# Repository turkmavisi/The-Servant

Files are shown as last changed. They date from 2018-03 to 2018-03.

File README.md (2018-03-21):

# The-Servant

## Autonomous Garbage Collector Robot Project of JCN Electronics

The Servant Project includes the complete design, production and documentation processes of an autonomous garbage collector robot which detects undesirable objects in its own specified area and clears the area off from these undesirable objects by dropping them to its opponent’s field. The Servant is created as a scalable product prototype for mass production which belongs to JCN Electronics who is the virtual company that is founded and managed by the Project Team as Middle East Technical University Electrical and Electronics Engineering Undergraduate Senior Design (Dissertation) Project.

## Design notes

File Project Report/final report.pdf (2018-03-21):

## Table of Contents

## 1. EXECUTIVE SUMMARY

Encyclopedia Britannica defines the word engineering as “the application of science to the

optimum conversion of the resources of nature to the uses of humankind”. In parallel to this

definition, throughout history; to do research; to design, invent and manufacture products in

order to satisfy our everlasting needs and demands within the restrictions of our limited

resources have been among the main purposes of engineering. Consequently, our expanded

horizons have led us to feel the need to have robots that will do the hard work instead of us,

and maybe, for us.

In the last decade, as the robot systems became more and more widespread, autonomous

devices have experienced a rise of attention. The applications of autonomous devices are

numerous. Therefore, studying these concepts and designing and manufacturing a product

that can achieve this, are among the needs of today’s academic and industrial world.

Through this document, JCN, a newly established company aiming at simple, yet elegant

solutions to real life problems according to the needs of their customers, presents their main

solution steps: Their conceptual design for the problem of constructing a robot that will clear

its own area off undesirable objects.

The final product incorporates several subsystems such as motion system, field and position

system, target and fence detection system, catching and throwing system and power

system. The philosophy of the design is based on simplicity and robustness, as a commercial

product would be restricted mostly by these specifications. The proposed system comes into

prominence with its detection system and its effective catching and throwing system as the

rest of the report will show.

JCN has been working on this project extensively and continuously for the last 7 months. To

design and manufacture such systems require a substantial amount of knowledge about

signal processing, control theory and robotics. Therefore, JCN, as a company proud to work

on such a project and each and every team member is happy to contribute to it. Not only is

this project a road to synthesize the theoretical knowledge they have acquired so for but

also, an opportunity to learn a lot more.

## 2. BRIEF INTRODUCTION

Recently founded by five ambitious engineers, JCN is a company focusing on robotics,

control systems and digital signal processing. Each of these five group members has different

major fields of study and they encompass a wide range of professional interests. Believing

that the interdisciplinary study is an integral part of their problem solving process, JCN is

glad to have this diversity in the company.

For their first project, JCN is now working on to design and build “A robot which clears its

own area off undesirable objects.” In this project, JCN provides their customers with a

Servant robot, adjustable field and adjustable objects, along with the deliverables that come

with the end product. The main operation of the product is to detect the undesirable object

with the help of the sensors, catch it and throw it to the other field without colliding the

fence or the other robot. The design basically consists of the following subsystems:

- Microcontroller subsystem consisting of two Arduino Nano to integrate all

individual subsystems under a complete system,

- A power subsystem to distribute the power to the product efficiently,
- A motion subsystem consisting of the main body of the vehicle, motors and

motor driving circuitry,

- A field detection subsystem consisting of four CNY sensors at the corners of the

robot to detect the borders of the field,

- An object detection subsystem consisting of two ultrasonic sensors to detect the

targets (undesirable objects) and the fence,

- A catch and throw subsystem consisting of a creative mechanic design working

with one servomotor and 2 stepper motors.

The main aim of this report is to give the detailed information about JCN’s final product for its latest project. In this report; after presenting the company and briefly explaining the main system, each sub-block has been presented. Technical details about the product, specifications and test results have been given. Moreover; deliverables and overall cost of the product have been discussed.

## 3. COMPANY ORGANIZATION

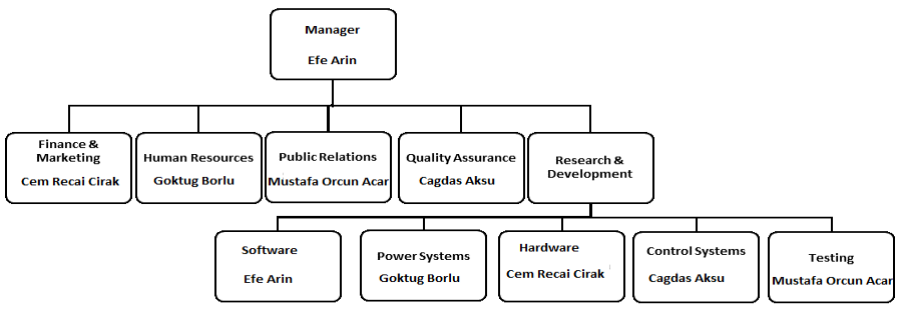
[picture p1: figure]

Figure 1: Company Organization

Hata! Başvuru kaynağı bulunamadı. shows the Company Organization. In this Figure, the divisions are done using the conceptual relationship in the company. All five members have responsibilities in the Management and Research & Development parts.

## 4. DESIGN DESCRIPTION

JCN has designed the robot having 4 sub-blocks, which are intended to function for

specific jobs to meet the all requirements of the project. The sub-systems perform

individually, and they are controlled by common or different DC motors and microcontroller.

Main Requirements:

- Robots should not exceed the boundaries and fence
- Speed and detection is important because of the limited time and opponents.
- No hard wiring is allowed cross the field boundaries.

Before going to next step, main hardware components of the servant project are;

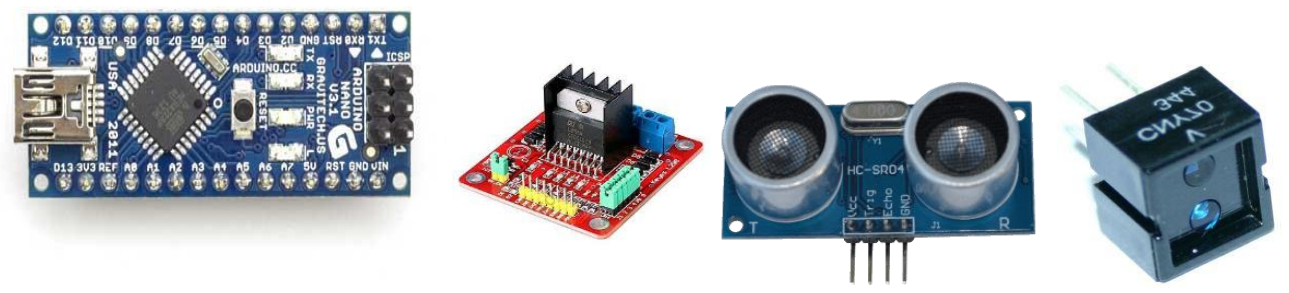
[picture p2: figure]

Figure 2 Main components of the Servant

### 4.1 System Modules

Motion System and Microcontroller: This system is basic response to movement of

robot. There is not complex as other three subsystems but it is important as them. Therefore

JCN has spared necessary time to develop this system. The purpose of this system is to enable

the robot move stably when makes detection and disposing. This system contains two high-

torque DC motors with their wheels and one dummy wheel

For microcontroller part, JCN decided to use two separate ardunio nano to perform

multiple task functionality in inexpensive way. Why is this way inexpensive? The answer is

quite open; for multitasking functionality; high –level microcontrollers such as FPGA should

be used. It is already known that these type microcontrollers are so expensive when compared

with two ardunio nano.

One of the ardunios is used to perform motor driving, target and field detection (takes

the data coming from ultrasonic and contrast sensors).Other one’s usage purpose is

controlling catch and throw mechanism. The advantage of using this method is that we divide

the controls of two main subsystems to two different microcontrollers. By using this way

when the servant throws the garbage, it can continue to detection facility.

Detection System: Since the project is mainly based on the detection of the wastes,

much more time was spend and also much more research was made for this part of the system

modules when is compared other three system modules. At the beginning of the project many

solutions were thought such as image process, ultrasonic sensors etc. by shareholders of JCN.

At the end much more economic and easy way were determined that using ultrasonic sensors

and for this system module. In addition to this for the field detection contrast sensors are used.

Catch and Throw System: This sub-system is designed to send the wastes to

opponent side. This system module is second important part of the whole system. Design

consists of two alternative solutions according to the distance of servant to fence. If the

servant is close enough to fence, then it uses drop functionality otherwise it uses throw

mechanism.

Power System: When this module was designed, JCN considered two main things:

power consumption and high sensitive to environment. Safety is also important but in these

days most of the batteries types can meet this requirement. According to these consideration

power system has designed and completed

### 4.2 System Algorithm

The individual sub systems will be discussed in detail analytically and critically,

however to give the initial and basic logic of the device functioning to the customers, ASMD

type of system algorithm can be examined as in Figure 3.

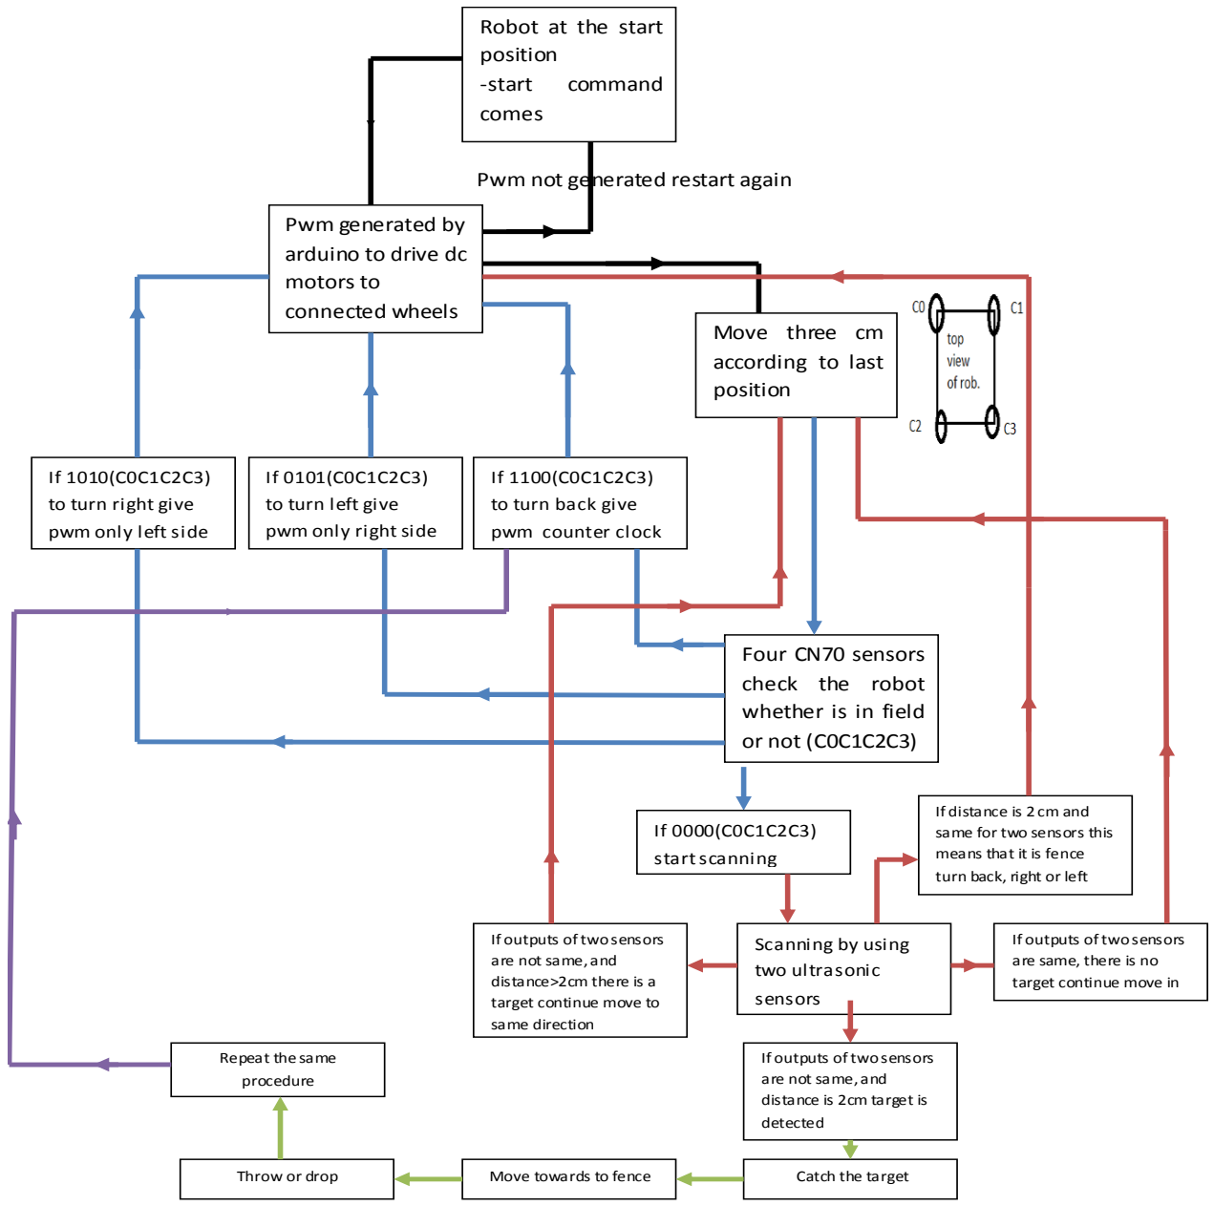
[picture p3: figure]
Pwm not generated restart again; Robot at the start position; -start; command; comes; Pwm generated by arduino to drive dc motors to connected wheels; Move three cm according to last position; Four CN70 sensors check the robot whether is in field or not (C0C1C2C3); If 0101(C0C1C2C3) to turn left give pwm only right side; Scanning by using two ultrasonic; sensors; If 1010(C0C1C2C3) to turn right give; pwm only left side; If 1100(C0C1C2C3) to turn back give; pwm counter clock; start scanning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

Figure 3 ASMD chart of general design

## 5. ANALYSIS OF THE SUBSYSTEMS

The design of the project is composed of 4 sub-blocks, which are motion subsystem, detection subsystem, catch and throw mechanism, finally power system. Before giving detailed information about these systems, you can see the flow diagram of the servant project as below:

START

Initialize the pins and pwm generator to move

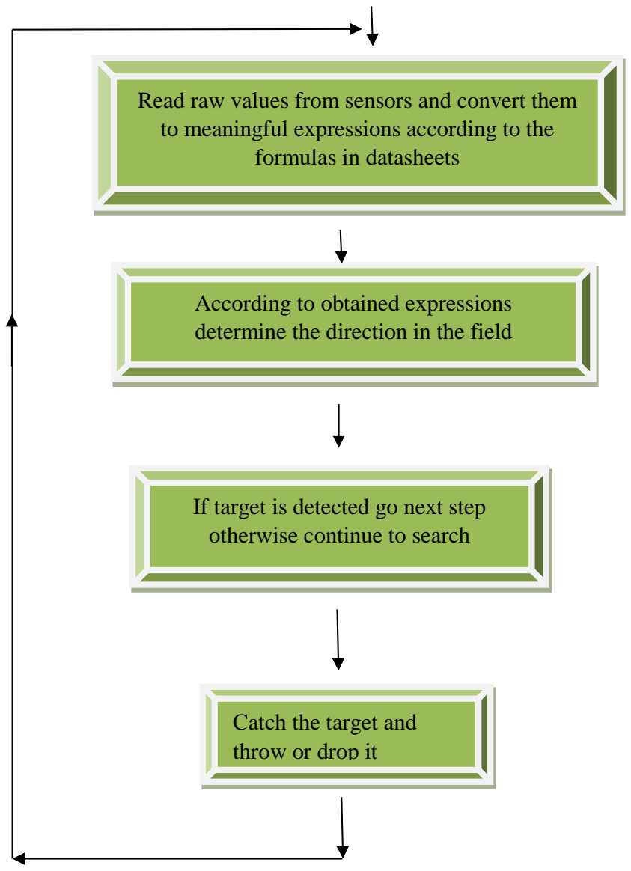
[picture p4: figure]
formulas in datasheets; According to obtained expressions determine the direction in the field; If target is detected go next step otherwise continue to search; Catch the target and throw or drop it

Read raw values from sensors and convert them to meaningful expressions according to the

### 5.1. Motion and Microcontroller Subsystem

The general solution logic can be seen from the chart below.

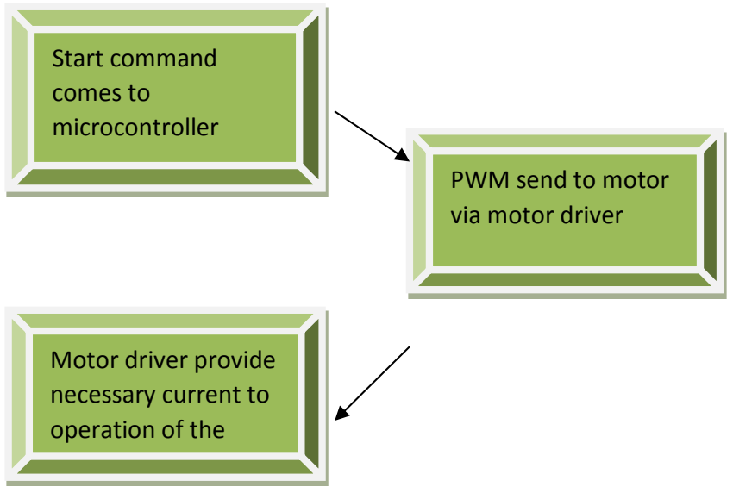
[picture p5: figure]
Start command comes to microcontroller; PWM send to motor via motor driver; Motor driver provide necessary current to operation of the

L298N Motor drive:

Due to that the motor will be requiring more current than the microcontroller pin can

provide, this unit is needed for motor driving. This chip contains dual Full Bridge, which

accept standard TTL logic levels and drive inductive loads such as relays, solenoids, DC and

stepping motors.

The L298N is designed to provide bidirectional drive currents of up to 4 A at voltages

to 46 V. The L298N provides low saturation voltages and over temperature protection. In

addition to this, it provides logical “0” input voltage up to 1.5 V in other words it has high

noise immunity.

The L298N IC receives signals from the microprocessor and transmits this signal to

the motors. It has two voltage pins, one of which is used to draw current for the working of

the L298N and the other is used to apply voltage to the motors. The L298N switches it output

signal according to the input received from the microprocessor. For example: If the

microprocessor sends a 1(digital high) to the Input Pin of L298N, then the L298N transmits a

1(digital high) to the motor from its Output Pin. An important thing to note is that the L298N

simply transmits the signal it receives. It does not change the signal in any case.

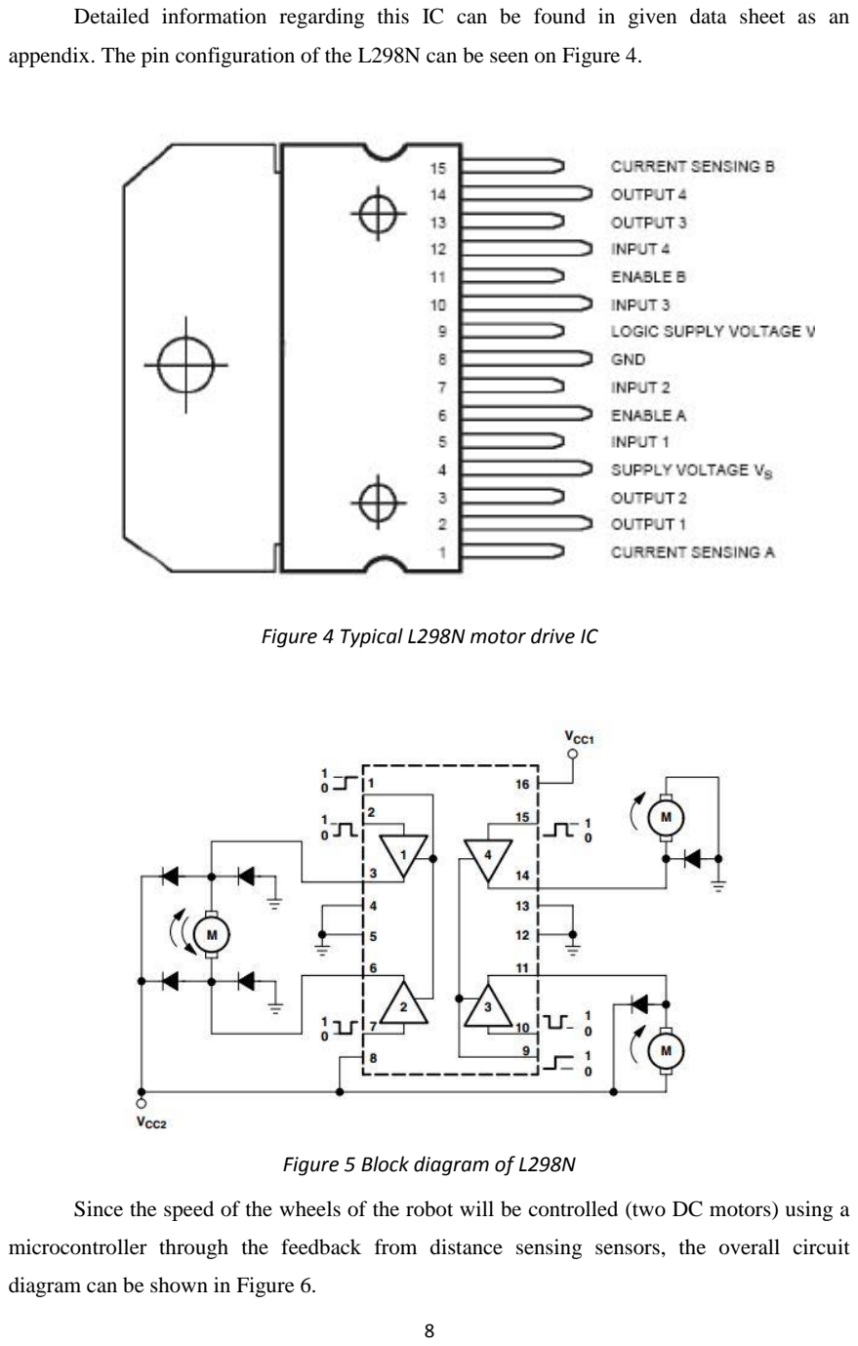
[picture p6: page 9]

Detailed information regarding this IC can be found in given data sheet as an

appendix. The pin configuration of the L298N can be seen on Figure 4.

Figure 4 Typical L298N motor drive IC

Figure 5 Block diagram of L298N

Since the speed of the wheels of the robot will be controlled (two DC motors) using a

microcontroller through the feedback from distance sensing sensors, the overall circuit

diagram can be shown in Figure 6.

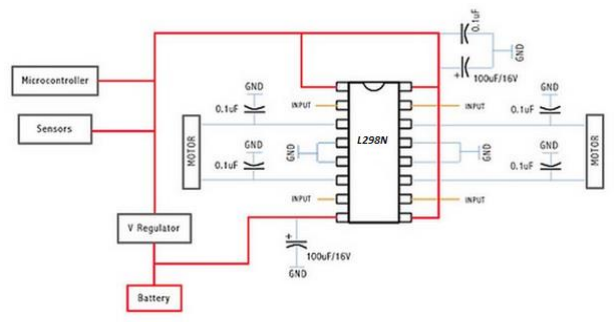
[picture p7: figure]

Figure 6 Circuit diagram of motor driver

According to sensors data microcontroller sends a command (pwm) to driver to made

scanning process on the given field. Detailed information will be given in detection part but

basic principle of the turn right or left based on given pwm to left and right DC motors. In

other words when pwm is only given to right motors, the servant turns left side otherwise

turns right.

Microcontroller & PWM:

The speed for the following mode of operation will be controlled by a well-known

technique of Pulse Width Modulation (PWM). Pulse width modulation is a method for

reducing the amount of power delivered to a DC motor. Instead of reducing the voltage

operating the motor (which would reduce its power), the motor’s power supply is rapidly

switched on and off. The percentage of time that the power is on determines the percentage of

full operating power that is accomplished. This type of motor speed control is also easier to

implement with digital circuitry. It is typically used in mechanical systems that will not need

to be operated at full power all of the time.

The first sub system to be implemented in the project was this sub block (motion system), and

JCN has completed this part with no error rate. This has been achieved thanks to the

successfully planned conceptual design of this sub system, as discussed in detail in the test

procedures & results part of this report.

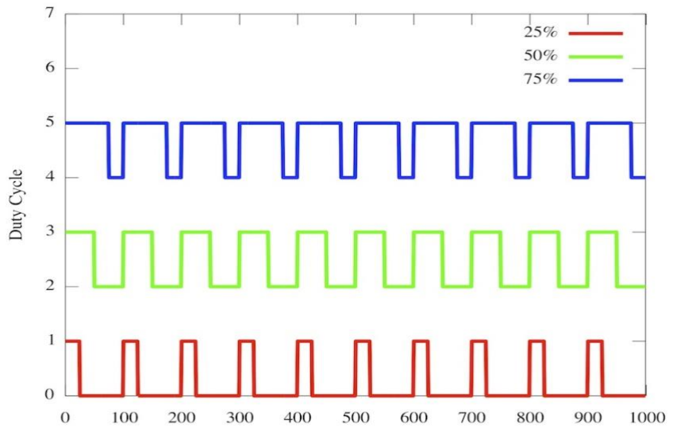
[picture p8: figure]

To implement this method, Arduino has been preferred among other types of

microcontrollers due to the advantages it offers, some of which can be examined as below;

- Inexpensive
- Arduino boards are relatively inexpensive compared to other microcontroller platforms. The

least expensive version of the Arduino module can be assembled by hand, and even the pre-

assembled Arduino modules cost less than $50. Due to these information, it was logical to use

Arduino for cost minimization purposes.

- Cross-platform
- The Arduino software runs on Windows, Macintosh OSX, and Linux operating systems.

Most microcontroller systems are limited to Windows.

- Simple programming environment
- The Arduino programming environment is easy-to-use, and flexible, which reduces the

amount of time allowed for the coding.

Figure 7 PWM with different duty cycle.

### 5.2. Detection Subsystem

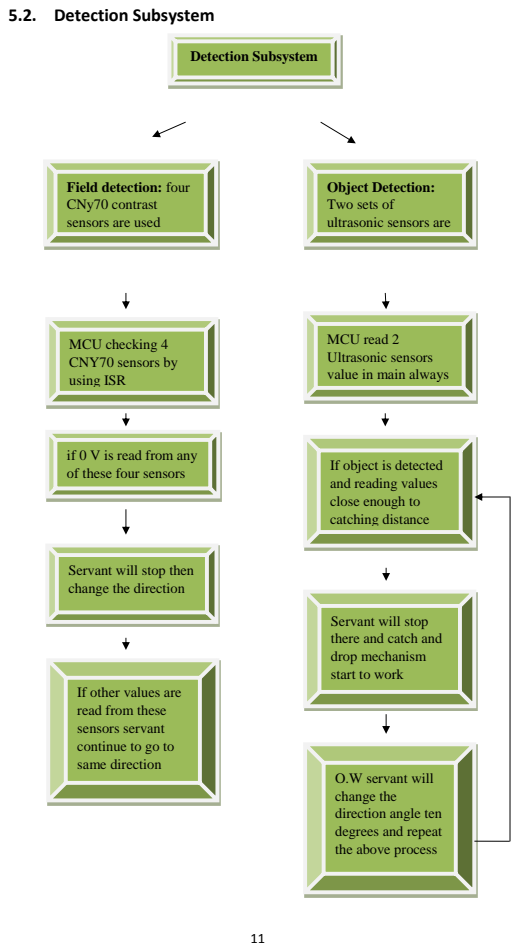
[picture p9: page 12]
MCU checking 4 CNY70 sensors by using ISR; Detection Subsystem

Field detection: four
CNy70 contrast
sensors are used

Object Detection:
Two sets of
ultrasonic sensors are

MCU read 2
Ultrasonic sensors
value in main always

if 0 V is read from any
of these four sensors

If object is detected
and reading values
close enough to
catching distance

Servant will stop then
change the direction

Servant will stop
there and catch and
drop mechanism
start to work

If other values are
read from these
sensors servant
continue to go to
same direction

O.W servant will
change the
direction angle ten
degrees and repeat
the above process

Detection subsystem was divided in two main blocks. These blocks are field detection

and target detection.

Field detection subsystem: is used to identify field by remaining within the field borders and

to specify the position of the robot and the direction that it fronts on to. In this part, mainly

two CNY70 contrast sensors are used. These sensors are emplaced on the leading edge of

robot base 1 cm above the field floor as one on the leftmost and one on the rightmost. In

addition, for the sake of to ease the detection process, floor of the field is designed in white

color with 2.5 cm width black borders to make a contrast between field and borders. During in

motion, the robot checks analog data came from both CNY70 sensors continuously and

interprets it as digital data by comparing it with a threshold value which is decided according

to experimental measurements. (Using analog data provides capability to make a reasonable

comparison with an adjustable threshold value for deciding the contrast level in different

environments by neutralizing the undesired distractive environmental effects.) In general case,

values read from both sensors are expected under the threshold. Remaining all three cases are

considered as primary emergency cases and less than one of these cases related immediate

action algorithm is run. These algorithms stern to the robot into the field back and end the

emergency case in the shortest time possible. Brief description about CNY70; is a reflective

sensor that includes an infrared emitter and phototransistor in a leaded package which blocks

visible light. You can see CNY70 and test configuration from Figure 8.

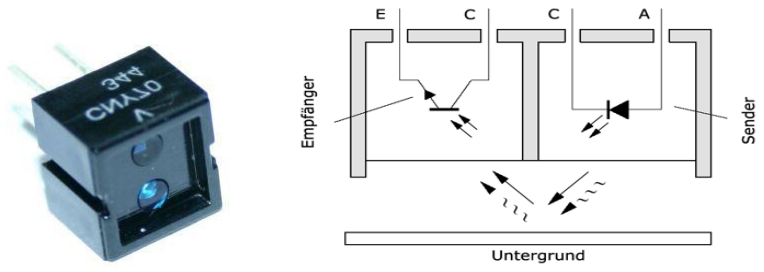
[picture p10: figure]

Figure 8 Working principle of contrast sensor

Object Detection Subsystem: Object detection subsystem is used to search and detect the

targets and the fence. This subsystem consists of two nested parts as fence detection and

target detection. In this subsystem, mainly two Ultrasonic sensors are used. The working

principle of ultrasonic sensors is given on Figure 9.

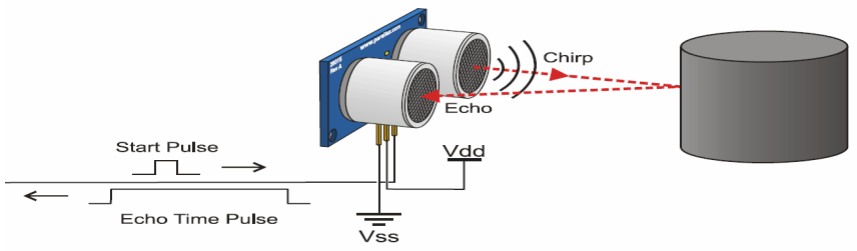
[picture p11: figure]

Figure 9 Working principle of ultrasonic sensor

Object detection subsystem also consists of two separate parts:

Fence Detection: Fence detection part aims to avoid possible crashes between the robot and

the fence while searching for targets and to detect and to close through the fence with the right

angle after a target was captured. The robot decides that the fence is detected if the higher

sensor data implies that there is an object.

Target Detection: Target detection part aims to search and to find the targets. In this part,

there are three possible cases. First, if the lower sensor implies that there is no object, then the

robot decides that there is no target in the scope. In this situation servant change direction

angle and scan again object in the range of ultrasonic sensors. This process is continued until

the object is found or 360 degrees are completed. If object cannot found in this process

servant continue to movement in random direction 2 seconds then repeat the same process.

Second, if both sensors imply that there is an object and their data values approximately the

same, then the robot decides that there is no target in the scope and the fence is detected.

Third, if both sensors imply that there is an object and their data values strictly different

(expectedly data value comes from the lower sensor is greater), then the robot decides that a

target is detected. When target is detected MCU control the distance whether garbage closes

enough to catch mechanism. If it is close catch and drop/throw mechanism will start otherwise

servant go to object until the sufficient distance will be caught

### 5.3. Catch and Throw Subsystem

Before going deep in this subsystem, Figure 10 and Figure 11 are given in order to help you to construct the real mechanism in your brain before reading detailed explanations.

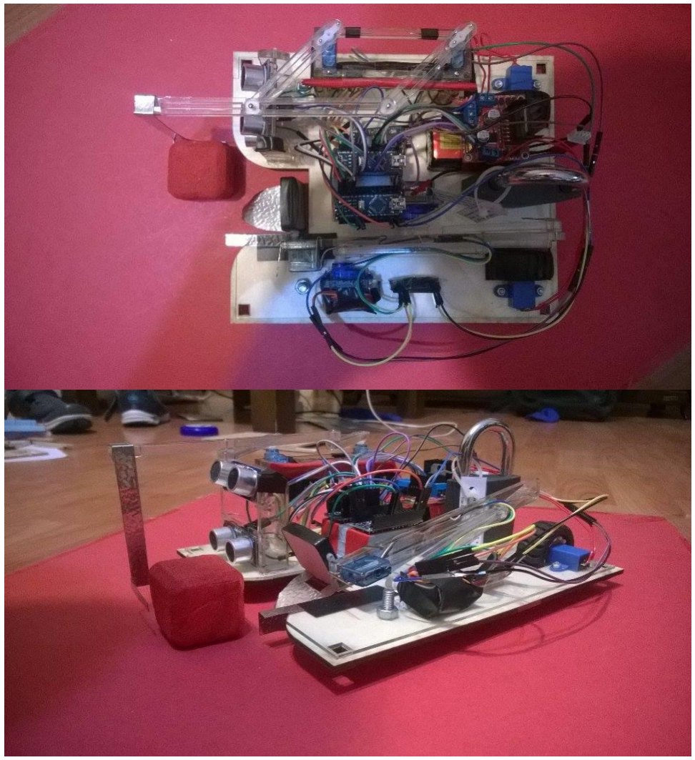
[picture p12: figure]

Figure 10

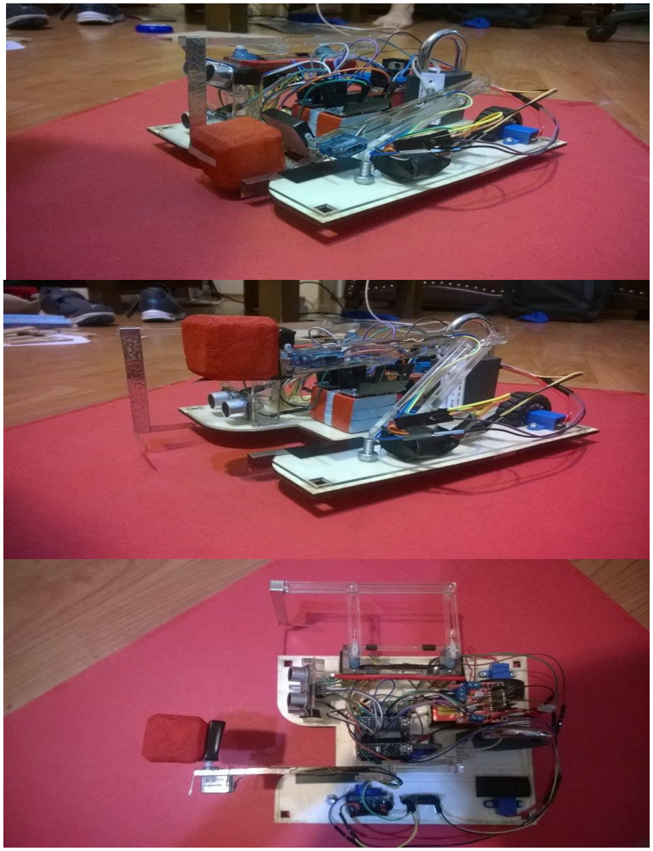
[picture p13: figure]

Figure 11

As you can see from Figure 10 and Figure 11, detailed catch and drop/throw mechanism

described step by step with given photos. Firstly, servant approaches the target until to exact

catch distance is caught. When this process complete, MCU send the start command to motors

of catch arm then catch arm opened to take to garbage to lift platform. When catch arm is

closed, coming order is send to lifting arm’s motors. Garbage is lifted up then drops it over

the fence.

Catch: As a catch mechanism The Servant will use a simple arm that sweeps the garbage

through the platform which lifts the garbage over the fence for the throw or drop mechanism

after detection of garbage The Servants goes through it and servo completes one cycle.

Thanks to the pin located to the catch arm and which moves inside the circular rail, garbage

will be swept through inside of the robot.

Drop: After catching the garbage ‘The Servant’ will drop the garbage by moving to just

behind the fence. The Servant has a simple, single servo motor controlled drop mechanism.

Basically servo just lifts the garbage. Since there will be a spring between platform and lifting

arm the garbage will stay aligned through the direction of lift arm up to pin which is fixed to

the chassis. Whenever the front point height of the platform reaches to the pin, the platform

alignment will start to be destroyed since the front point stops rising while the platform-lifting

arm connection keeps rising. It is expected that before the lifting arm-platform connection

reaches to its top point the garbage slips and drops down.

### 5.4. Power Subsystem

The power system consists of three main subunits; the battery, the battery charger and the

cables that carry the power. The cables of the product are standard robotics cables and the

currents that are carried in the device are insignificant and will pose no overloading problems.

The charger is another simple equipment related to this subsystem and works well with the

battery. Instructions for the charger can be found in the user manual given in the appendix.

The most critical technology in the power system is the battery.

The battery included in the device is a 3-cell, 12 V, 1100 mAh Li-Po battery.

Table 1: Power Consuming Devices in the Robot

Device | Usual Current Demand (mA) at 5 V | Max. Current Demand (mA) at 5 V
Arduino Nano x2 | ~100 mA (5 V) | Same
Ultrasonic Sensor x2 | 5 mA (5 V) | Same
Contrast Sensors x4 | 10 mA (5 V) | Same
Motor Driver | 1.5 mA (5 V) | 2.2 mA (5 V)
DC Motor x2 | 140 – 320 mA (5 V) | 320 mA (5 V)
Servo Motor x5 | 20 mA (5 V) | 140 mA (5 V)
Total | 631.5 – 991.5 mA (5 V) | 1592.2 mA (5 V)

## 6. TECHNICAL DETAILS AND TESTS

Testing the equipment is the critical point for a design project. For specific equipment, tests should confirm the usability and the compatibility for the whole project. JCN has conducted several tests in different time periods of the overall design process. Some of them were performed more than once along the design project. The tests that the JCN has conducted were related to the subsystems and their components.

### 6.1 Detection Subsystem

For the detection subsystem, ultrasonic and the contrast sensors are used. For the fence and waste detection two imbricated ultrasonic sensors were used. They are placed with an angle of 10 degree between the vertical axis in the Figure 2.

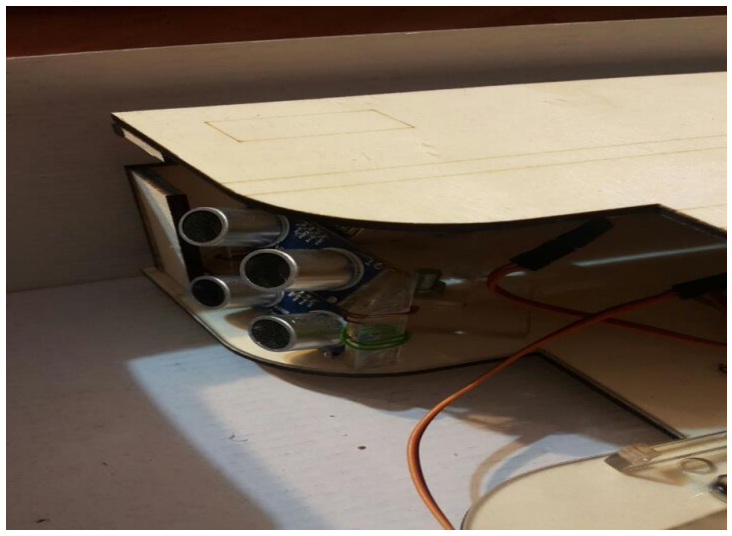
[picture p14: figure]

Figure 12 Placement of the ultrasonic sensors

In order to test the ultrasonic sensors, objects are placed at different distances and results are observed. After several trials, it is obtained that those sensors are able to distinguish four-centimeter-particles from 80 cm distance. This was a sufficient result for the gardener project considering the standards for the fence and the waste. Finally they are tested with the field and the wastes. The problems seen during the fence detection are solved by adjusting the algorithm.

On the other hand, CNY 70 contrast sensors, which can be seen on Figure 2, are used for the field and the border detection. Four of them are placed at the corners of the robot. The working principle of a contrast sensor is giving different output signals according to the field under it. Basically, it determines whether the field under it is black or white.

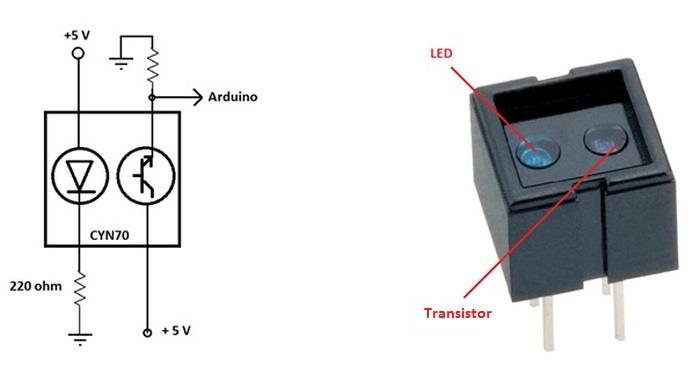
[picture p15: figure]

Figure 13 CNY 70

Those CNY 70 sensors are tested with the motion system. Results were satisfying since the robot was able to stay in the field by returning when a black border is detected.

### 6.2 Catch and Drop Subsystem

There are 5 servos and 1 DC motor in this subsystem. Two of the servos (4.3 gr, 0.8 kg/cm) are for catch system, one of them (4.3 gr, 0.8 kg/cm) is used for drop mechanism, and other two of the servos (9 gr, 1.7 kg/cm) are used for lifting mechanism

Servo motors should be tested in terms of torque and angle. Because of the lack of the necessary equipment such as torque wrench, those tests were conducted by the hand and observations, and the results were promising at first. After the implementation of the robot, it is seen that the subsystem works properly with the real wastes.

### 6.3 Motion Subsystem

The acceleration and speed control of the vehicle is an important issue. The vehicle should be able to move to search and grab the target and stop without crashing to the waste or the fence. Moreover, the speed of the vehicle should vary while searching and carrying. Actually this can be achieved with the control of DC engines which are used to move the vehicle. This control is satisfied by the PWM method. By the PWM method, the average voltage sent to motor, thus the speed of the motor is adjusted.

DC motors were tested with additional weight in order to implement the actual weight at first and with the real components then. In those tests, it is seen that the robot can travel 2 meters in approximately 10 seconds which corresponds the 90rpm with the wheels which have 4.2 cm diameter. Results showed that DC motors can satisfy the needs of the project in terms of speed.

### 6.4 Communication Test for Two Arduinos

In the servant project two arduinos were utilized. While one of them is responsible of DC motors used in motion subsystem, the other one is managing the catch and drop mechanism. The main problem of two arduinos working together in a project is the floating problem. JCN developed a protocol in order to prevent that problem to occur.

## 7. COST ANALYSIS

Budget limitation for The Servant project is $ 150. Approximate cost analysis per The Servant

can be seen in the Table 1.

Table 1: Approximate Cost Analysis Per ‘The Servant’

Equipment | Quantity | Total Price ($)
Microcontroller | 2 | 4.00
Battery | 1 | 8.09
DC Motor Driver Module | 1 | 1.75
DC Motor + Wheel | 2 | 5.04
Free Wheel | 2 | 3.00
Stepper Motor | 2 | 2.88
Stepper Motor Driver Module | 2 | 1.94
Servo Motor | 1 | 1.72
Contrast Sensor | 2 | 0.60
IR Distance Sensor | 2 | 8.58
Accelerometer | 1 | 0.99
Blank PCB | 1 | 0.96
Construction | 1 | 10.00
Field + Fence | 1 | 10.00
User Manuel | 1 | 0.10
Steampunk Gear Set | 1 | 2.00
Evil Eye Talisman | 1 | 0.10
Lace | 1 | 1.50
Cable + Soldering Wire | | 1.50
Others | | 2
Total | | 66.75

## 8. DELIVERABLES

The Servant box will include following items:

- The Servant robot itself
- Field
- Fence
- 3 x Target
- Evil eye talisman
- Lace
- User manual

## 9. APPENDIX

### 1. USER MANUAL

“The Servant” package includes:
- The robot equipped with 2 DC motors, 2+2 caster wheel system, 4 contrast sensors at the corners, 2 ultrasonic sensors, a Li-Po battery, Arduino Nano.
- 3 targets
- Battery charger
In case of any missing parts please contact to the supplier.

INSTRUCTIONS

- Charge the Li-Po battery with the provided battery charger. Set the current value in the range [0.5A, 1A].
- There is a cable available for battery charging.
- Set the field and fence.
- Set the robot on.
- When the level of battery is low, the robot sounds for warning. Then make the robot off and charge it again.
- DO NOT CHARGE the robot while the robot is on.

MALFUNCTIONS

There are no recorded malfunctions of this product.
In case of any malfunctioning of the parts (sensors,wheels..etc.) please contact to the supplier. DO NOT fix the damaged parts by yourself

LIMITATIONS

- The sensors' may show poor performance near reflective objects.
- The device is not suitable for rough surfaces.
- DO NOT use any cleaning supplies on the device
- The device may contain small parts not suitable for children under age 5.

Supplier contact information:
E-mail: jcnelectronicscorporation@gmail.com

### 2. L298 DUAL H-BRIDGE MOTOR DRIVER MODULE SPECIFICATIONS

- | Driver | : L298
- | Driver power supply | : +5V~+46V
- | Driver peak current | : 2A
- | Logic power output Vss | : +5~+7V (internal supply +5V)
- | Logic current | : 0~36mA
- | Controlling level: Low -0.3V~1.5V, high | : 2.3V~Vss
- | Enable signal level: Low -0.3V~1.5V, high | : 2.3V~Vss
- | Max drive power | : 25W (Temperature 75 ℃)
- | Working temperature | : -25℃~+130℃
- | Dimension | : 60X54mm
- | Driver weight | : ~48g

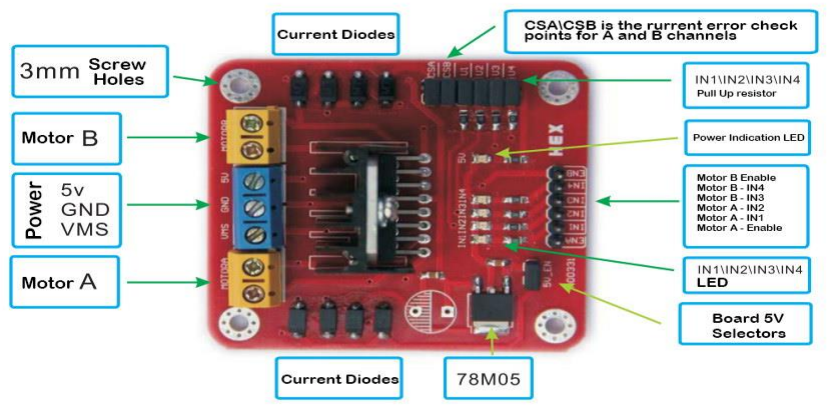
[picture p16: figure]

### 3. CODES FOR ARDUINO 1

#include <SoftwareSerial.h>

//Sensor pins

byte trigPinLow = 7; //Lower sendor trig pin

byte echoPinLow = 8;

byte trigPinUp = 3; //Upper sensor trig pin

byte echoPinUp = 4;

//Motor pins

//Directions (Straight movement R0&L0=0 R1&L1=1)

int L0 = A0;

int L1 = A1;

int R0 = A2;

int R1 = A3;

//PWM

byte pwmL = 5;

byte pwmR = 6;

//Previous turn (0 no prev turn 1 right 2 left)

byte turnside = 0;

//CNY70 pins

byte FL = 9;

byte BL = 10;

byte BR = 11;

byte FR = 12;

//Communication pin

byte com = 13;

//Reset pins

int resetm = A7;

int resetf = A6;

void setup() {

//Serial port

Serial.begin (9600);

Serial.println("Start");

//Interrupt pin

// attachInterrupt(digitalPinToInterrupt(2), CNYCHECK, LOW);

//Sensor pins

pinMode(trigPinLow, OUTPUT);

pinMode(echoPinLow, INPUT);

pinMode(trigPinUp, OUTPUT);

pinMode(echoPinUp, INPUT);

//Motor pins

//Directions

pinMode (L0, OUTPUT);

pinMode (L1, OUTPUT);

pinMode (R0, OUTPUT);

pinMode (R1, OUTPUT);

//PWM

pinMode (pwmL, OUTPUT);

pinMode (pwmR, OUTPUT);

//Initializations

analogWrite (pwmR, 0);

analogWrite (pwmL, 0);

//CNY70 pins

pinMode (FL, INPUT);

pinMode (BL, INPUT);

pinMode (BR, INPUT);

pinMode (BL, INPUT);

//Communication pin

pinMode (com, OUTPUT);

digitalWrite (com, LOW);

//Reset pins

pinMode (resetf, OUTPUT);

analogWrite(resetf,0);

}

void(* resetFunc) (void) = 0;//declare reset function at address 0

void loop() {

Serial.println("Restart");

FINDGARBAGE();

WAIT(); // open catch

GOGARBAGE();

WAIT(); // close catch

FINDFENCE();

WAIT(); // drop

NEXTPREPARE();

}

void CNYCHECK () {

STOP();

int cnyval = digitalRead(FL)+2*digitalRead(BL)+4*digitalRead(BR)+8*digitalRead(FR);

randomSeed(millis());

int wai = random(100,200);

switch(cnyval){

//Front cases

case 1 :

TURNRIGHT();

delay(wai);

STOP();

break;

case 8 :

TURNLEFT();

delay(wai);

STOP();

break;

case 9 :

GOBACK();

delay(300);

if(random(1)) TURNRIGHT();

else TURNLEFT();

delay(wai);

STOP();

break;

//Back cases

case 2 :

GOSTRAIGHT();

delay(100);

TURNRIGHT();

delay(wai);

GOSTRAIGHT();

delay(300);

STOP();

break;

case 4:

GOSTRAIGHT();

delay(100);

TURNLEFT();

delay(wai);

GOSTRAIGHT();

delay(300);

STOP();

break;

case 6:

GOSTRAIGHT();

delay(100);

if(random(1)) TURNRIGHT();

else TURNLEFT();

delay(wai);

GOSTRAIGHT();

delay(300);

STOP();

break;

}

}

boolean DISTANCECOMPARE(){

Serial.println("Distance compare");

//each cm is 30

//return 0 nothing

//return 1 garbage detect

byte garbage=0; //Garbage detection

if(DISTANCELOW()<750){

for(int i=0 ; i<10 ; i++){

long low = DISTANCELOW();

delay(100);

long up = DISTANCEUP();

delay(100);

if (abs(low-up) > 120) garbage++;

}

if (garbage > 6) return HIGH;

else return LOW;

}

}

long DISTANCELOW (){

long data=0;

digitalWrite(trigPinLow, LOW);

delayMicroseconds(2);

digitalWrite(trigPinLow, HIGH);

delayMicroseconds(10);

digitalWrite(trigPinLow, HIGH);

data=pulseIn(echoPinLow, HIGH)/2;

return data;

}

int DISTANCELOWAVG () {

Serial.println("Distancelowavg");

int a=0;

for (int i=0; i<3; i++){

a=a+DISTANCELOW();

}

a=a/3;

Serial.println(a);

return a;

}

long DISTANCEUP (){

long data=0;

digitalWrite(trigPinUp, LOW);

delayMicroseconds(2);

digitalWrite(trigPinUp, HIGH);

delayMicroseconds(10);

digitalWrite(trigPinUp, LOW);

data=pulseIn(echoPinUp, HIGH)/2;

return data;

}

void FENCEALIGN(){

noInterrupts();

GOSTRAIGHT();

while (digitalRead(FL)||digitalRead(FR)) STOP();

do{

if (digitalRead(FL)){

TURNLEFT();

while(!digitalRead(FR)){}

STOP();

}

if (digitalRead(FR)){

TURNRIGHT();

while(!digitalRead(FL)){}

STOP();

}

}while (!(digitalRead(FL)&&digitalRead(FR)));

}

void FENCEDETECT(){

Serial.println("Fence detect");

delay(500);

randomSeed(millis());

int a = random (200);

long up;

if (a>100){

if (DISTANCEUP()>1200){

TURNRIGHT();

while(DISTANCEUP()>1200) {}

STOP();

}

up = DISTANCEUP();

do{

TURNRIGHT();

delay(50);

STOP();

}while(DISTANCEUP()>=up);

do{

up = DISTANCEUP();

TURNRIGHT();

delay(50);

STOP();

}while(DISTANCEUP()<up);

}

else{

if (DISTANCEUP()>1200){

TURNLEFT();

while(DISTANCEUP()>1200) {}

STOP();

}

up = DISTANCEUP();

do{

TURNLEFT();

delay(50);

STOP();

}while(DISTANCEUP()>=up);

do{

up = DISTANCEUP();

TURNLEFT();

delay(50);

STOP();

}while(DISTANCEUP()<up);

}

}

void FINDFENCE(){

Serial.println("Find fence");

FENCEDETECT();

//FENCEALIGN();

}

void FINDGARBAGE(){

Serial.println("Find garbage");

turnside=0;

while(!GARBAGEDETECT()){

RANDOMTRAVEL();

}

GARBAGEALIGN();

if(DISTANCELOWAVG()>400){

analogWrite (resetf,255);

delay(10);

analogWrite(resetf,0);

resetFunc();

}

}

void GARBAGEALIGN(){

Serial.println("Garbage allign");

delay(500);

// noInterrupts();

if(DISTANCELOWAVG()<300){

while (DISTANCELOWAVG()<300){

GOBACK();

delay(50);

STOP();

//if((digitalRead(BL)||digitalRead(BR))) digitalWrite(reset,HIGH);

}

STOP();

}

// interrupts();

}

boolean GARBAGEDETECT(){

Serial.println("Garbage detect");

if(DISTANCECOMPARE()){

if(turnside==1){

if (DISTANCELOWAVG()<200){

TURNRIGHT();

delay(60);

}

else{

TURNRIGHT();

delay(30);

}

STOP();

}

if(turnside==2){

if (DISTANCELOWAVG()<200){

TURNLEFT();

delay(60);

}

else{

TURNLEFT();

delay(30);

}

STOP();

}

if(DISTANCELOWAVG()<100){

// noInterrupts();

GOBACK();

delay(20);

STOP();

// interrupts();

}

| else {
// | noInterrupts();
| GOSTRAIGHT();
| delay(20);
| STOP();
// | interrupts();

}

if(DISTANCECOMPARE()) return HIGH;

else return LOW;

}

else return LOW;

}

void GOBACK (){

Serial.println("Go back");

delay(500);

digitalWrite (R0, HIGH);

digitalWrite (R1, LOW);

digitalWrite (L0, HIGH);

digitalWrite (L1, LOW);

analogWrite (pwmR, 245);

analogWrite (pwmL, 255);

}

void GOGARBAGE(){

Serial.println("Go garbage");

delay(500);

int a = DISTANCELOWAVG();

if(a>200 && a<750){

while(a>200 && a<750){

GOSTRAIGHT();

delay(20);

STOP();

a = DISTANCELOWAVG();

}

}

if(a>50 && a<=200){

while(a>50 && a<300){

GOSLOW();

delay(20);

STOP();

a = DISTANCELOWAVG();

}

Serial.println("closest ");

Serial.print(a);

}

if (a>50){

analogWrite (resetf,255);

delay(10);

analogWrite (resetf,0);

Serial.println("resetf");

resetFunc(); //call reset

}

}

void GOSLOW(){

Serial.println("Go slow");

digitalWrite (R0, LOW);

digitalWrite (R1, HIGH);

digitalWrite (L0, LOW);

digitalWrite (L1, HIGH);

analogWrite (pwmR, 100);

analogWrite (pwmL, 100);

}

void GOSTRAIGHT () {

Serial.println("Go straight");

delay(500);

digitalWrite (R0, LOW);

digitalWrite (R1, HIGH);

digitalWrite (L0, LOW);

digitalWrite (L1, HIGH);

analogWrite (pwmR, 245);

analogWrite (pwmL, 255);

}

void NEXTPREPARE(){

Serial.println("Next prepare");

delay(500);

GOBACK();

delay(200);

STOP();

randomSeed(millis());

int a = random(0,200);

if(a>100){

TURNRIGHT();

delay(100);

STOP();

}

else{

TURNLEFT();

delay(100);

STOP();

}

// interrupts();

RANDOMTRAVEL();

}

void RANDOMTRAVEL(){

Serial.println("Random Travel");

/*

int turnside

0 gostraight chosen

1 turnright chosen

2 turnleft chosen

*/

randomSeed(millis());

int a = random(0,250);

switch(turnside){

case 0 :

if (a<30){

GOSTRAIGHT();

delay(100);

STOP();

turnside=0;

}

else{

if(a>170){

TURNRIGHT()

;

delay(30);

STOP();

turnside = 1;

}

else{

TURNLEFT();

delay(30);

STOP();

turnside = 2;

}

}

break;

case 1 :

if (a<30){

GOSTRAIGHT();

delay(100);

STOP();

turnside=0;

}

else{

TURNRIGHT();

delay(30);

STOP();

turnside = 1;

}

break;

case 2 :

if (a<30){

GOSTRAIGHT();

delay(100);

STOP();

turnside=0;

}

else{

TURNLEFT();

delay(30);

STOP();

turnside = 2;

}

break;

}

}

void STOP (){

digitalWrite (R0, LOW);

digitalWrite (R1, LOW);

digitalWrite (L0, LOW);

digitalWrite (L1, LOW);

analogWrite (pwmR, 0);

analogWrite (pwmL, 0);

}

void TURNLEFT () {

Serial.println("Turn left");

delay(500);

digitalWrite (R0, LOW);

digitalWrite (R1, HIGH);

digitalWrite (L0,HIGH);

digitalWrite (L1, LOW);

analogWrite (pwmR, 245);

analogWrite (pwmL, 255);

}

void TURNRIGHT () {

Serial.println("Turn right");

delay(500);

digitalWrite (L0, LOW);

digitalWrite (L1, HIGH);

digitalWrite (R0,HIGH);

digitalWrite (R1, LOW);

analogWrite (pwmR, 245);

analogWrite (pwmL, 255);

}

void WAIT(){

Serial.println("Wait");

delay(500);

digitalWrite(com,HIGH);

digitalWrite(com,LOW);

delay(100);

pinMode(com,INPUT);

do{

}while(digitalRead(com)==LOW);

pinMode(com, OUTPUT);

digitalWrite(com,LOW);

}

### 4. CODES FOR ARDUINO 2

#include <Servo.h>

//Catch servos

Servo cf;

Servo cb;

//Lift servos

Servo lb;

Servo lf;

//Platform servo

Servo p;

//Communication pin

byte com = 13;

void setup() {

delay(1000);

//Interrupt pin

attachInterrupt(digitalPinToInterrupt(2), RESET, HIGH);

//Catch servos

cf.attach(3);

cb.attach(4);

//initializations

cf.write(10);

cb.write(25);

//Lift Servos

lb.attach(10);

lf.attach(11);

//Initializations

lb.write(45);

lf.write(130);

//Platform servo

p.attach(12);

//Initialization

p.write(20);

//Communication pin

delay (100);

pinMode (com, INPUT);

}

void(* resetFunc) (void) = 0;//declare reset function at address 0

void loop() {

WAIT1();

OPENCATCH();

WAIT2();

WAIT1();

DOWNPLATFORM();

CLOSECATCH();

UPPLATFORM();

WAIT2();

WAIT1();

UPLIFT();

DROPPLATFORM();

DOWNLIFT();

WAIT2();

}

void RESET (){

resetFunc(); //call reset

}

void CLOSECATCH (){

for (int i=157;i>5;i--){

cf.write(5+i);

cb.write(20+47*i/50);

delay(50);

}

}

void DOWNLIFT (){

for(int i=80;i>15;i--){

lb.write(30+i);

lf.write(148-8*i/7);

delay(50);

}

}

void DOWNPLATFORM (){

for(int i=20;i<80;i++){

p.write(i);

delay (50);

}

}

void DROPPLATFORM(){

p.write(100);

delay(500);

p.write(20);

}

void OPENCATCH (){

for (int i=5;i<157;i++){

cf.write(5+i);

cb.write(20+47*i/50);

delay(50);

}

}

void UPLIFT () {

for(int i=15;i<80;i++){

lb.write(30+i);

lf.write(148-8*i/7 );

delay(50);

}

}

void UPPLATFORM (){

for(int i=80;i>20;i--){

p.write(i);

delay (50);

}

}

void WAIT1 (){

do{} while(digitalRead(com)==LOW);

pinMode(com,OUTPUT);

digitalWrite(com,LOW);

}

void WAIT2 () {

digitalWrite(com,HIGH);

digitalWrite(com,HIGH);

delay(100);

pinMode(com,INPUT);

}

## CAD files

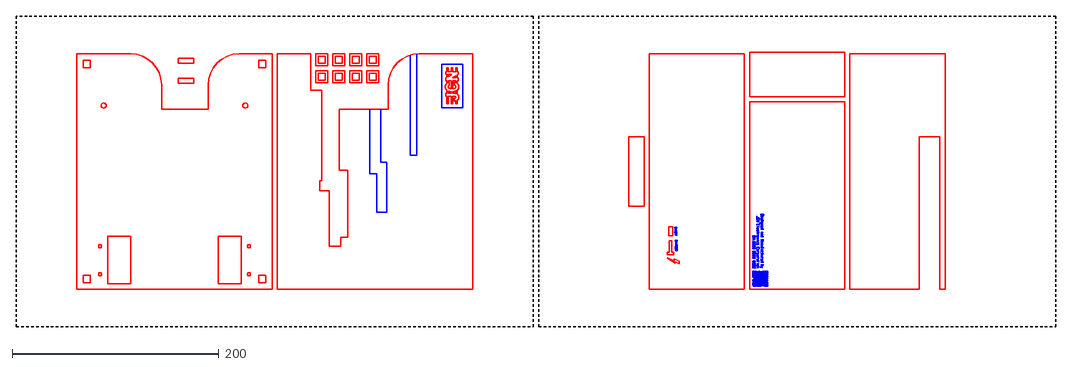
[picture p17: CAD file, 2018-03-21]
Laser Cut Drawings/DXF/4mm Kontrplak.dxf
1005.0 x 300.0

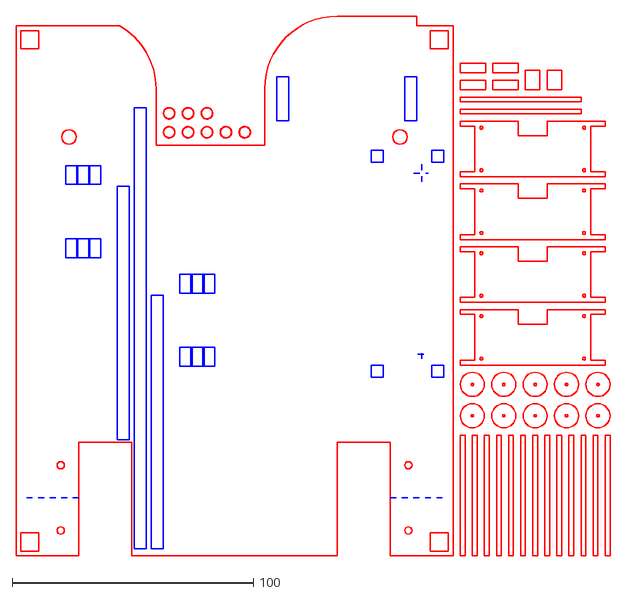
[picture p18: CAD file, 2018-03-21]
Laser Cut Drawings/DXF/2mm Plexi.dxf
246.0 x 223.5

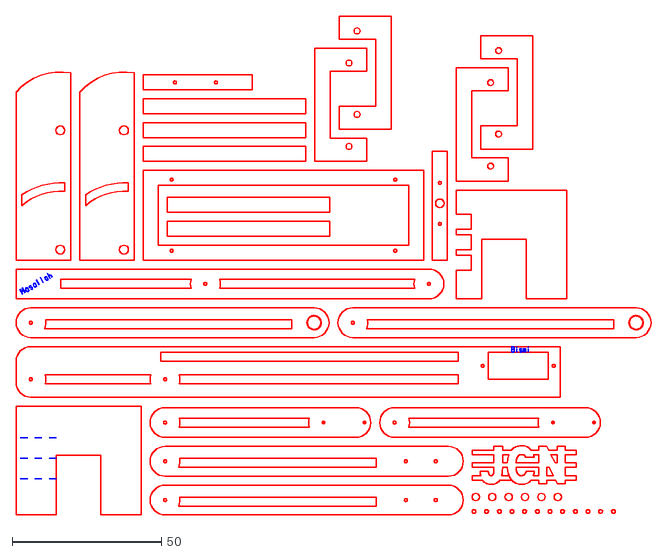
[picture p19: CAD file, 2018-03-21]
Laser Cut Drawings/DXF/5mm plexi.dxf
213.0 x 167.3

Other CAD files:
Laser Cut Drawings/DWG/2mm Plexi.dwg
Laser Cut Drawings/DWG/4mm Kontrplak.dwg
Laser Cut Drawings/DWG/5mm plexi.dwg
